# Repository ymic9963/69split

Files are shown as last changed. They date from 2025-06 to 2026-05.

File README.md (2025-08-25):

# 69SPLIT Keyboard
A split keyboard with 69 keys made for people that like to expose their I/O for any usecase.

## Costs
- Keycaps              = £3.38
- USB2.0 USB-C cable   = £0.80 
- Stabilisers          = £4.92
- Rubber feet          = £1.47
- Gateron Switches     = £15.79
- Left PCB Parts       = £10.97
- Left PCB             = £
- Right PCB Parts      = £5.36
- Left PCB             = £

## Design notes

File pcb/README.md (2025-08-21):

# PCB
Here is everything related to the PCB, with the design files for the two keyboard halves in `69split-left/` and `69split-right/`. The `3dmodels/` directory contains the 3D models I used to get the renders below. Read the `Circuit Description.md` file for a description on the design.

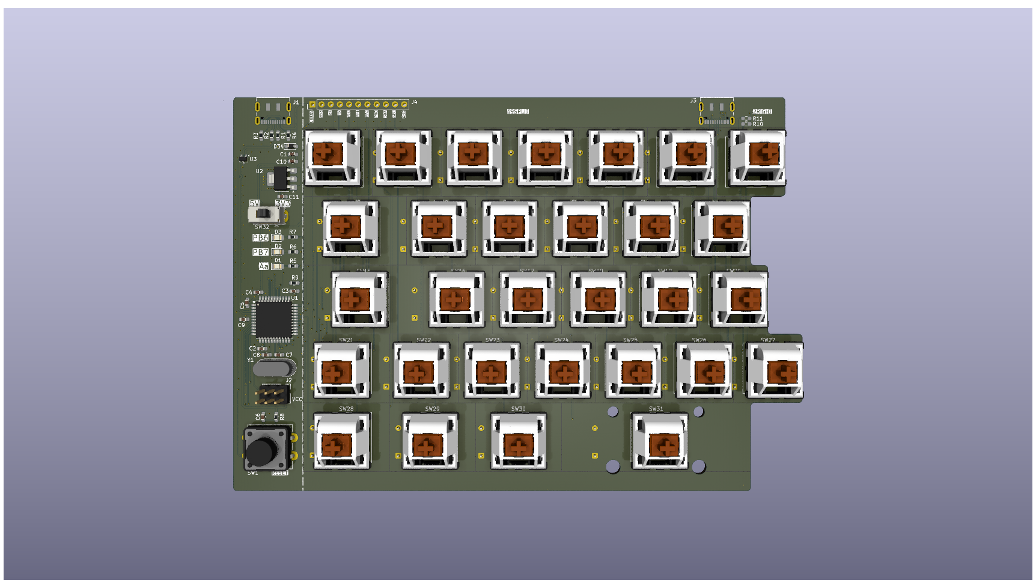
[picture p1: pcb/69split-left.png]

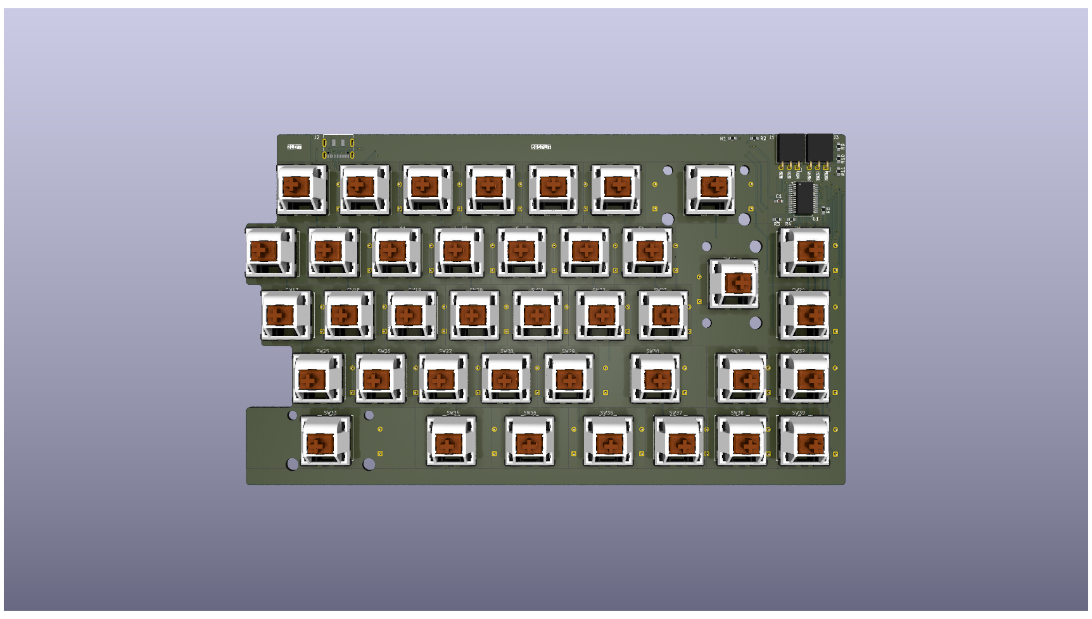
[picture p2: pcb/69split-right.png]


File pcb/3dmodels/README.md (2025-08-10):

# 3D Models
Used the `SW_Cherry_MX_PCB.stp` file from the [kiswitch](https://github.com/kiswitch/kiswitch/tree/main/library/3dmodels/3d-library.3dshapes) (Keyswitch KiCAD Livrary), and renamed it to get the models for the keyswitches used in the project. Place it in your KiCAD 3D model directory. Unfortunately I had to add offsets of X: -2.5mm, Y:-5mm, and Z:-0.5mm in all of the corresponding footprint files so that the models would align nicely.

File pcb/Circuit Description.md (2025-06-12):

# PROJECT-TITLE Circuit Description

## ATmega32U4
- Used this processor because it's compatible with QMK. Has a built in USB controller.
- 5V supply via USB.
- Minimum 500R current limiting resistors on GPIO pins as seen on Table 29-1 of the datasheet. 
- USB Implementation based on Section 21.3 Typical Application Implementation of datasheet.

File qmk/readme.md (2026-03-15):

# 69SPLIT

(image)

A split keyboard with 69 keys made for people that like to expose their I/O for any usecase.

* Keyboard Maintainer: [Yiannis Michael](https://github.com/ymich9963)
* Hardware Supported: rev1
* Hardware Availability: N/A

Make example for this keyboard (after setting up your build environment):

    make 69SPLIT

Flashing example for this keyboard:

    make 69SPLIT:default:flash

See the [build envronment setup](https://docs.qmk.fm/newbs_getting_started) and the [make instructions](https://docs.qmk.fm/getting_started_make_guide) for more information. Brand new to QMK? Start with our [Complete Newbs Guide](https://docs.qmk.fm/newbs).

## Bootloader

Enter the bootloader with the RESET button.

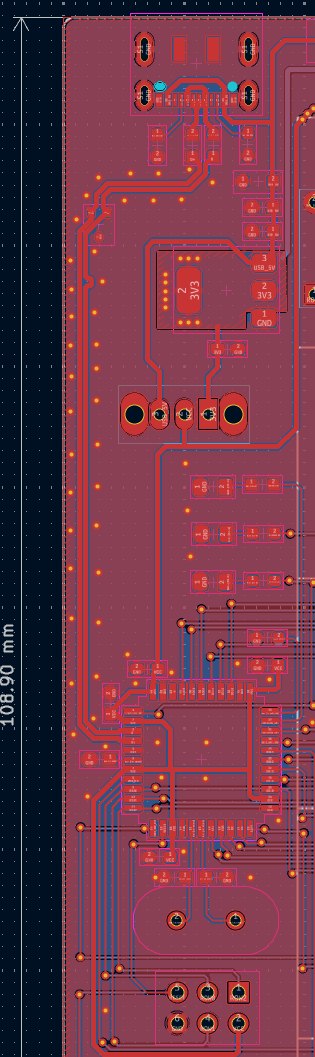
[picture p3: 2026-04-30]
pcb/69split-left/keeb-layout.png

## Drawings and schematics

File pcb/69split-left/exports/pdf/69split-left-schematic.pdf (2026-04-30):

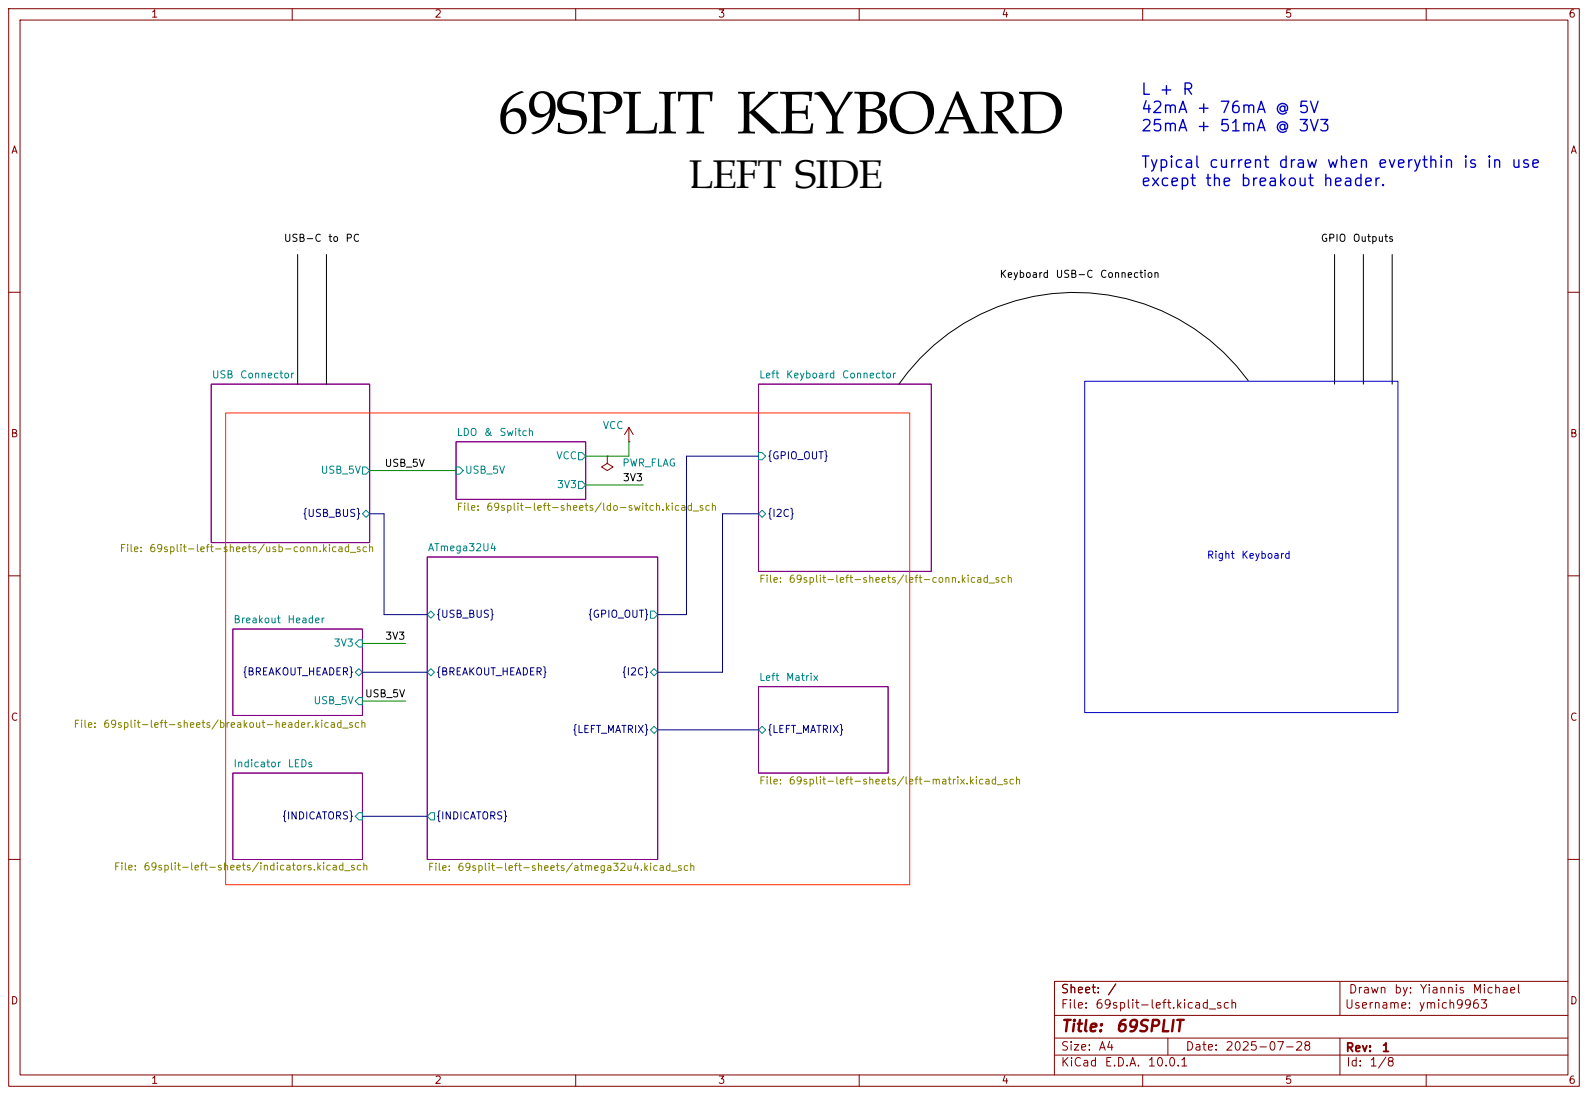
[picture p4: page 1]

Keyboard USB-C Connection 69SPLIT KEYBOARD L + R

Typical current draw when everythin is in use
except the breakout header. GPIO Outputs

{USB_BUS} USB_5V USB Connector File: 69split-left-sheets/usb-conn.kicad_sch

{I2C} Left Keyboard Connector File: 69split-left-sheets/left-conn.kicad_sch USB_5V

File: 69split-left-sheets/ldo-switch.kicad_sch

{BREAKOUT_HEADER} 3V3 USB_5V Breakout Header File: 69split-left-sheets/breakout-header.kicad_sch

{LEFT_MATRIX} Left Matrix File: 69split-left-sheets/left-matrix.kicad_sch

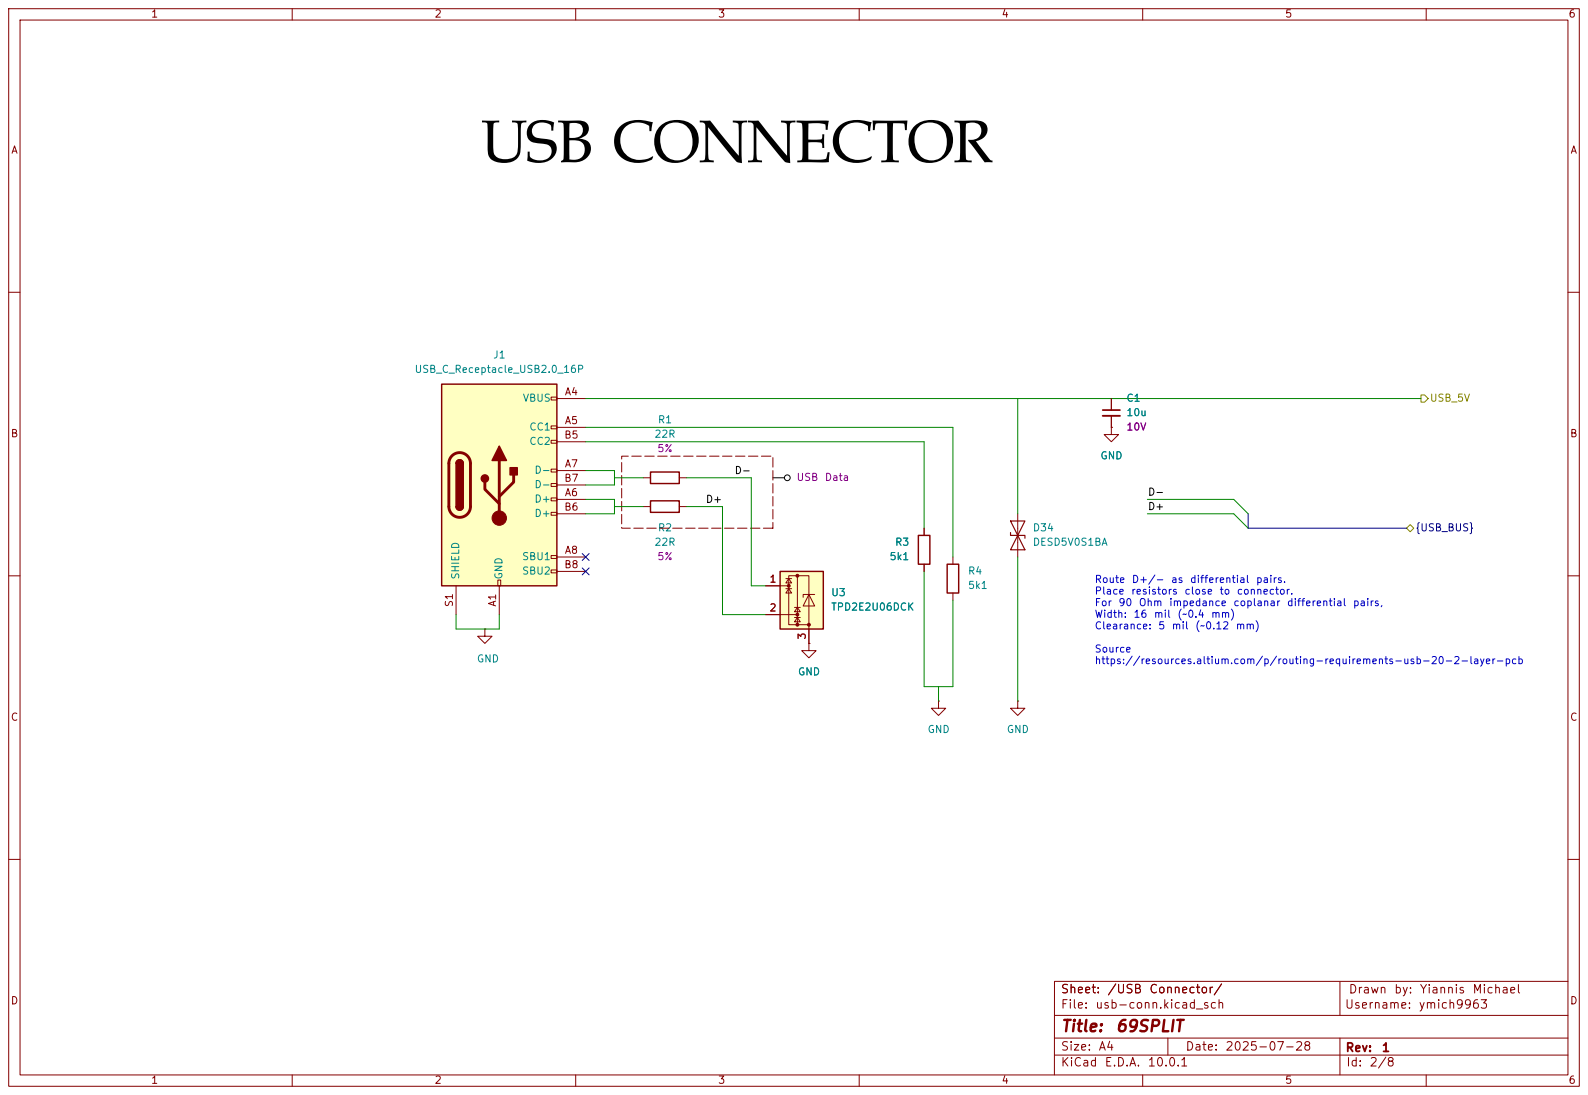
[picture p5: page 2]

Route D+/- as differential pairs. Place resistors close to connector. For 90 Ohm impedance coplanar differential pairs, Width: 16 mil (~0.4 mm) Clearance: 5 mil (~0.12 mm) Source https://resources.altium.com/p/routing-requirements-usb-20-2-layer-pcb U3

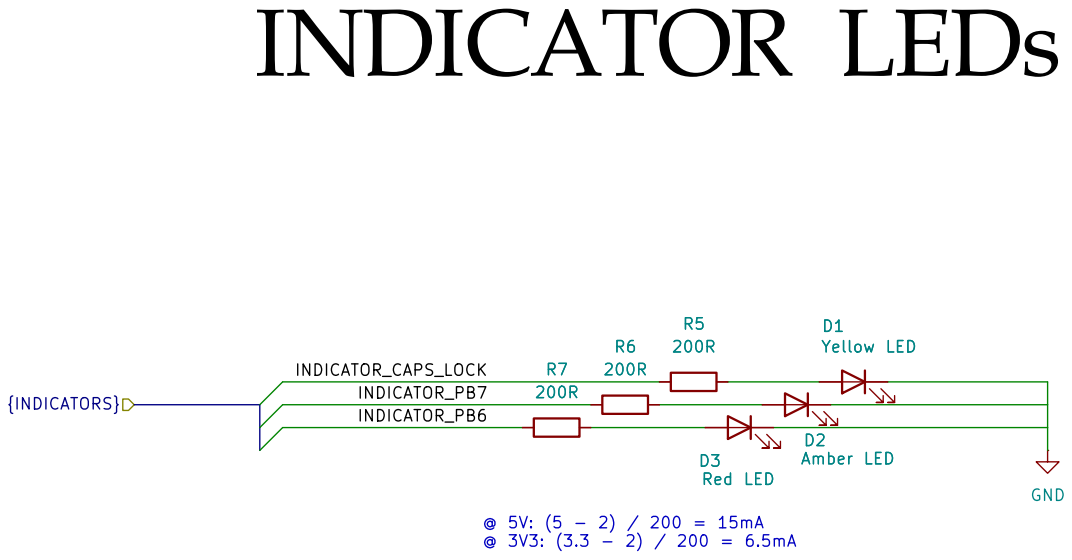
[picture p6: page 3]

Size: A5 | Rev: 1 | C Date: 2025-07-28
KiCad E.D.A. 10.0.1 | Id: 3/8

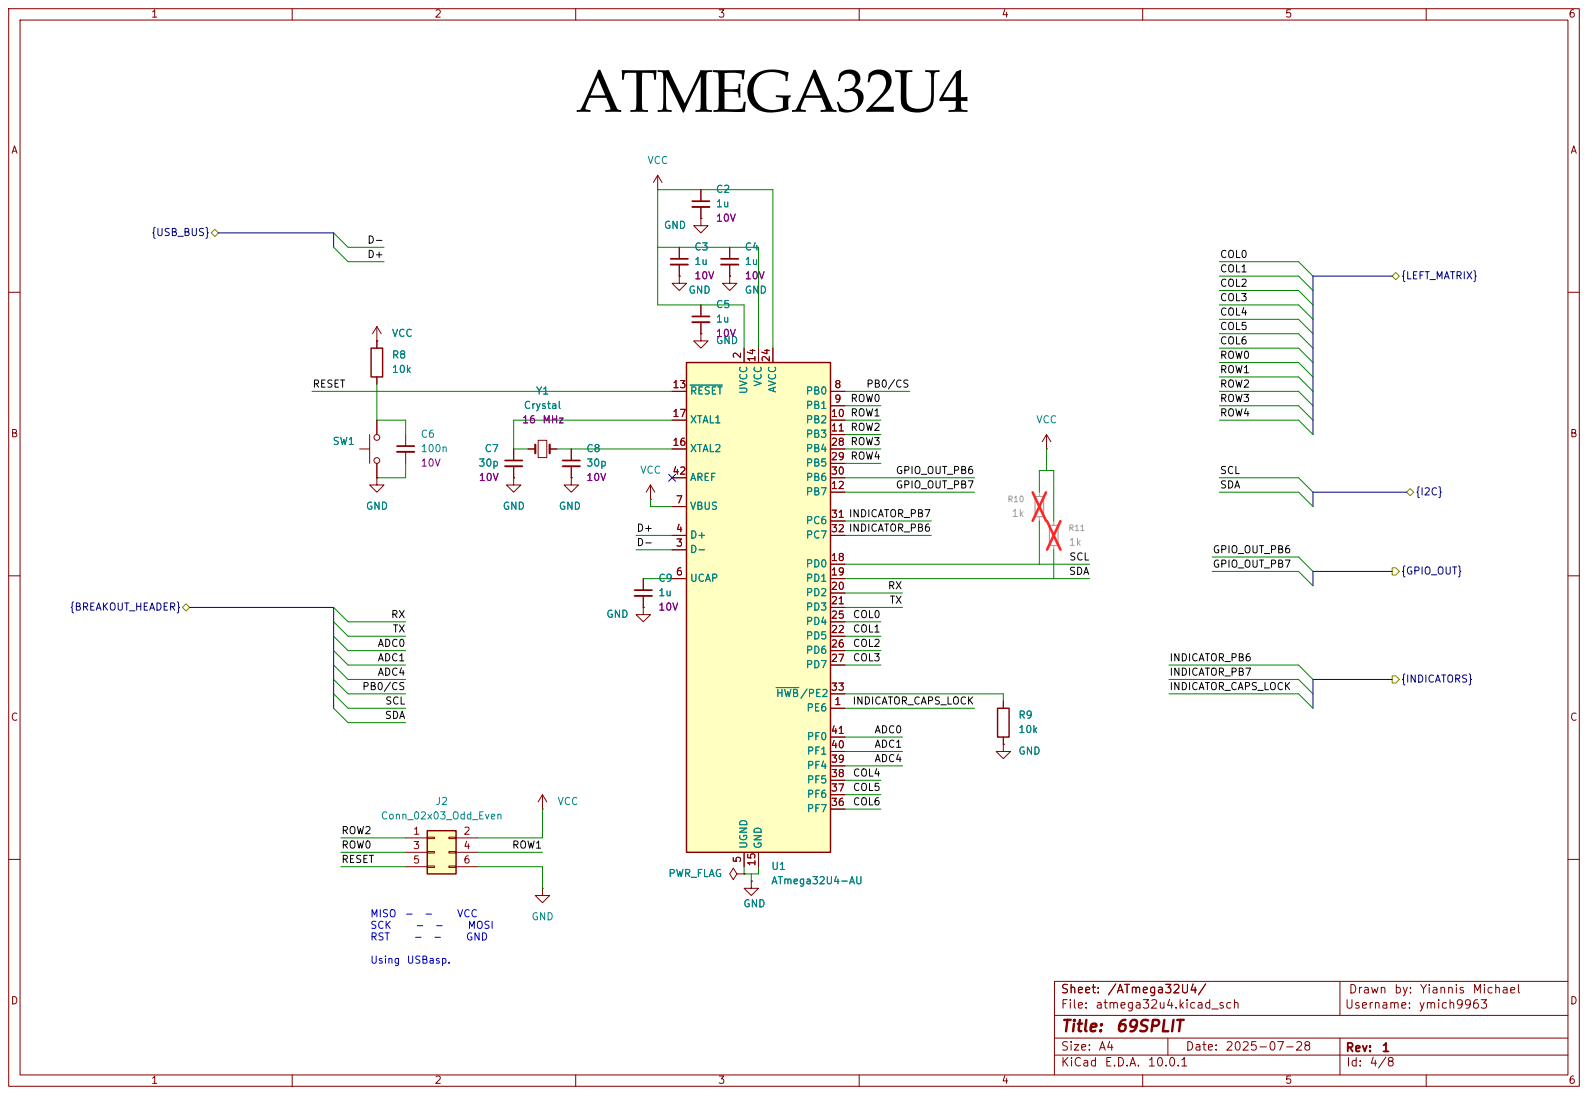
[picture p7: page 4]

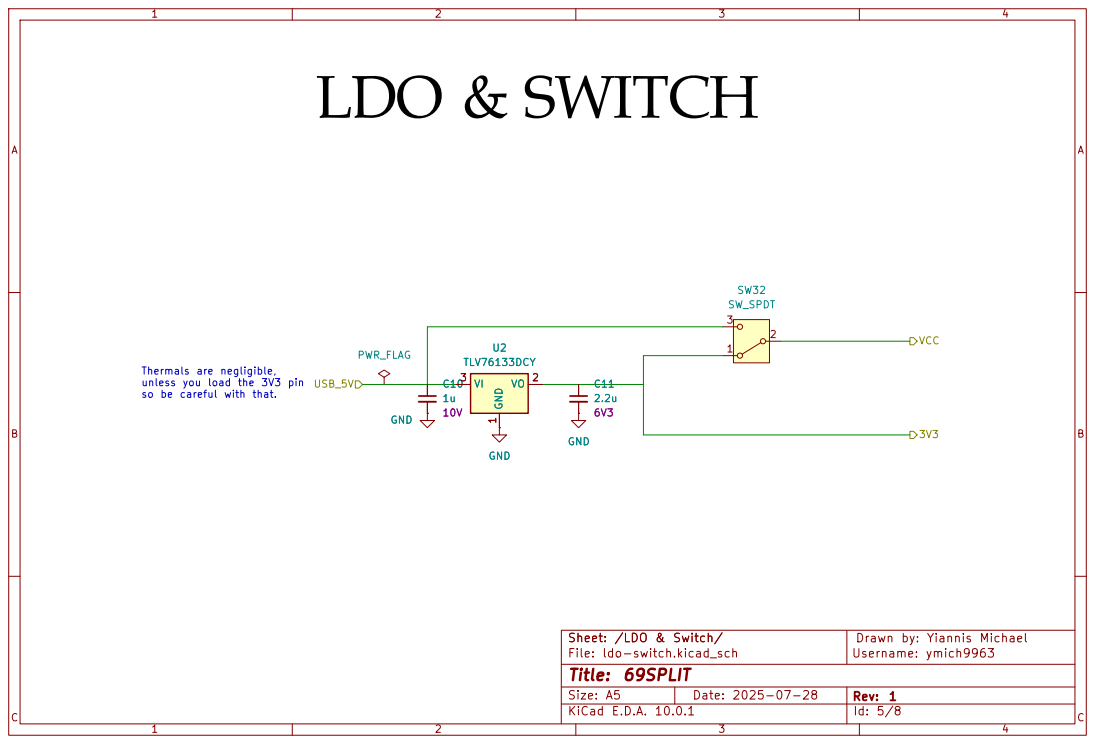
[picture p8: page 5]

Thermals are negligible, unless you load the 3V3 pin

Size: A5 | Rev: 1 | C Date: 2025-07-28
KiCad E.D.A. 10.0.1 | Id: 5/8

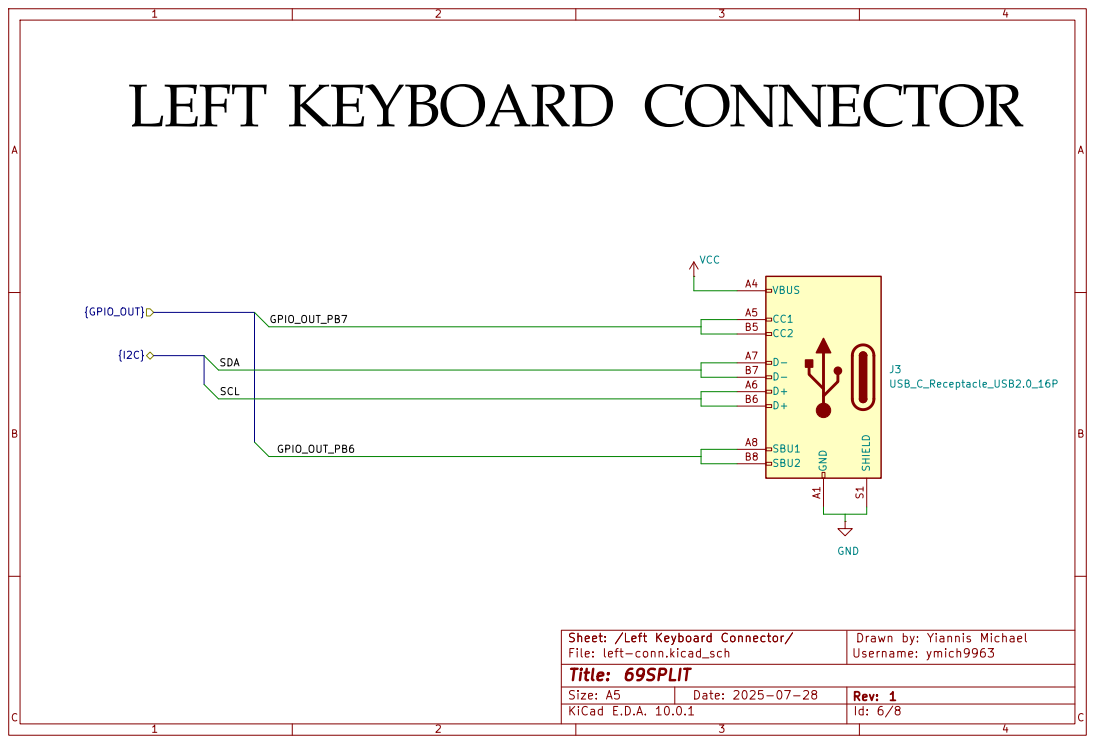
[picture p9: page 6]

Size: A5 | Rev: 1 | C Date: 2025-07-28
KiCad E.D.A. 10.0.1 | Id: 6/8

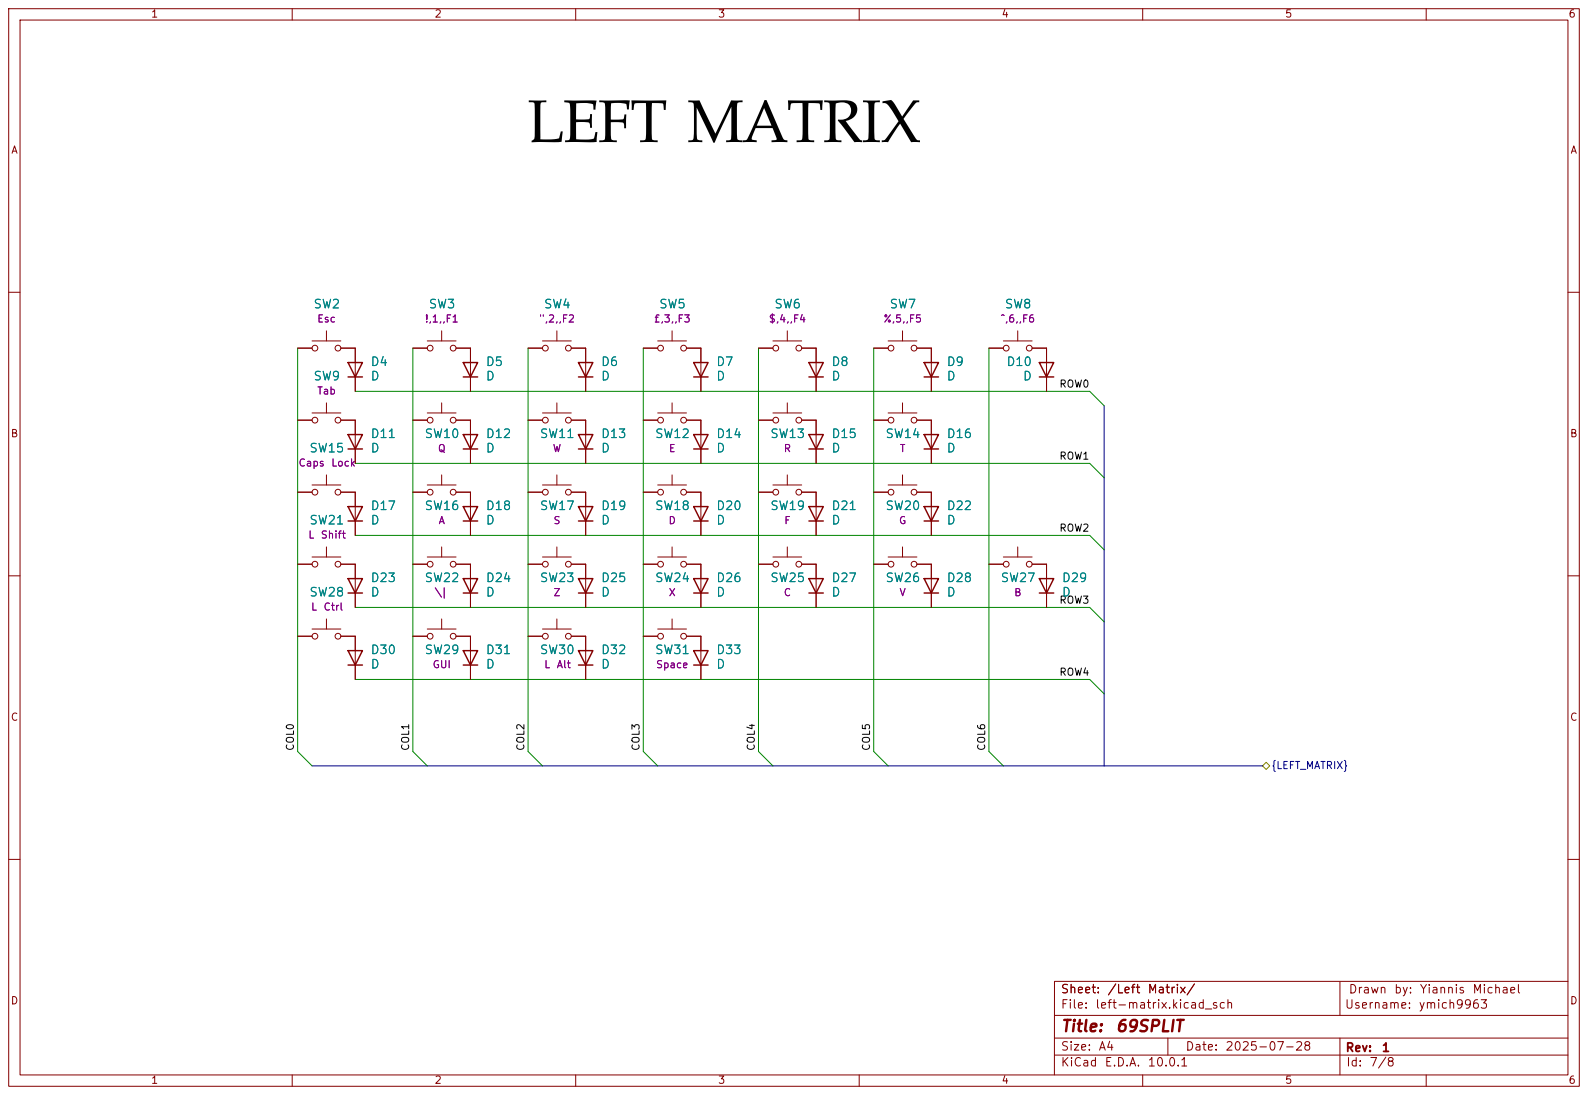
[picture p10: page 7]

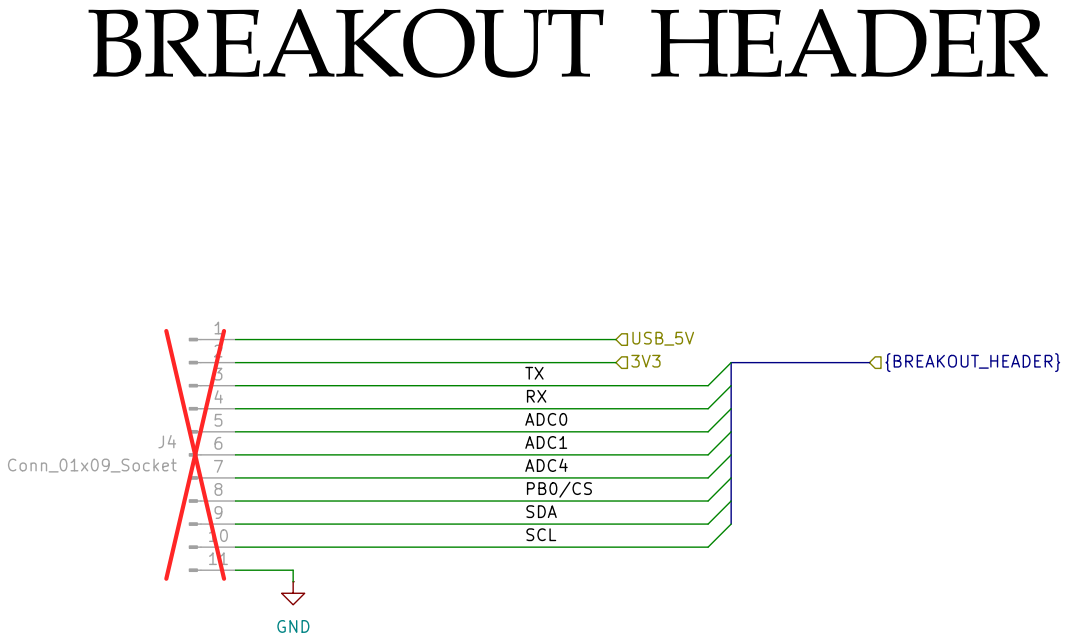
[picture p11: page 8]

Size: A5 | Rev: 1 | C Date: 2025-07-28
KiCad E.D.A. 10.0.1 | Id: 8/8

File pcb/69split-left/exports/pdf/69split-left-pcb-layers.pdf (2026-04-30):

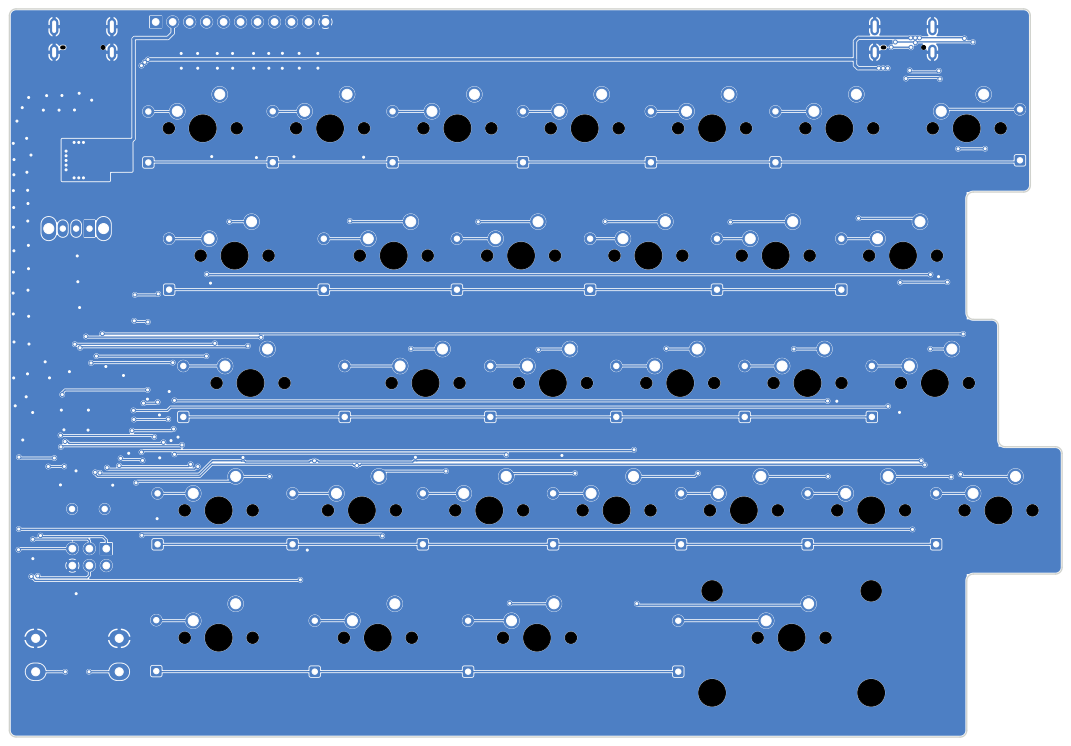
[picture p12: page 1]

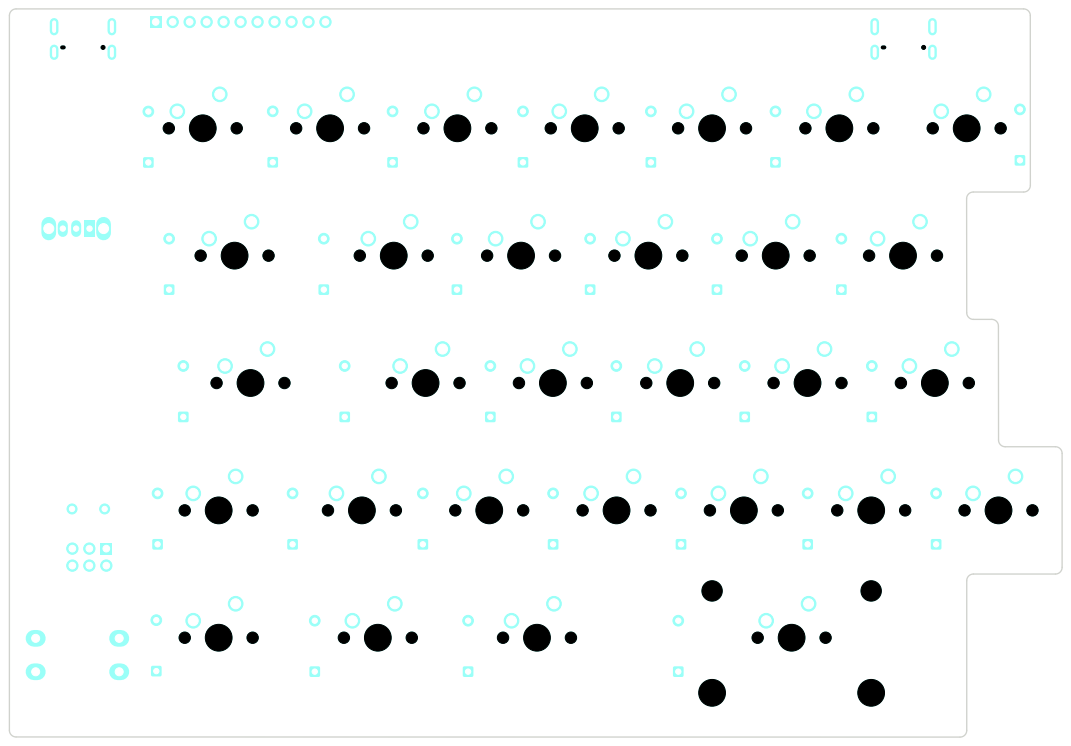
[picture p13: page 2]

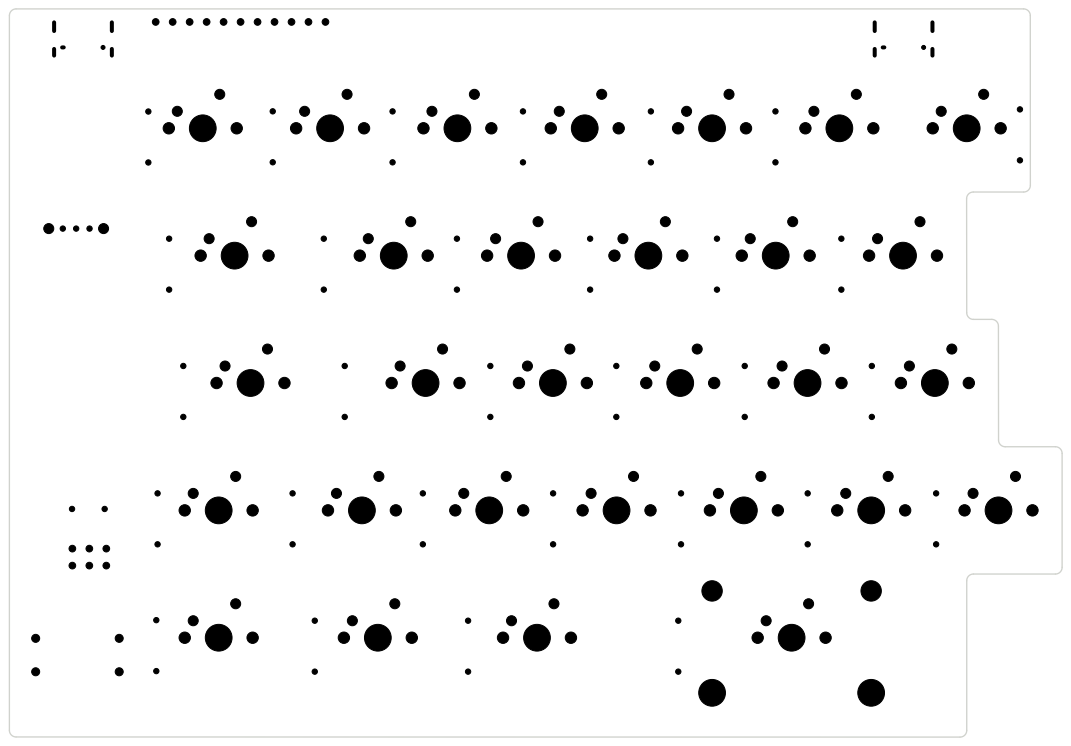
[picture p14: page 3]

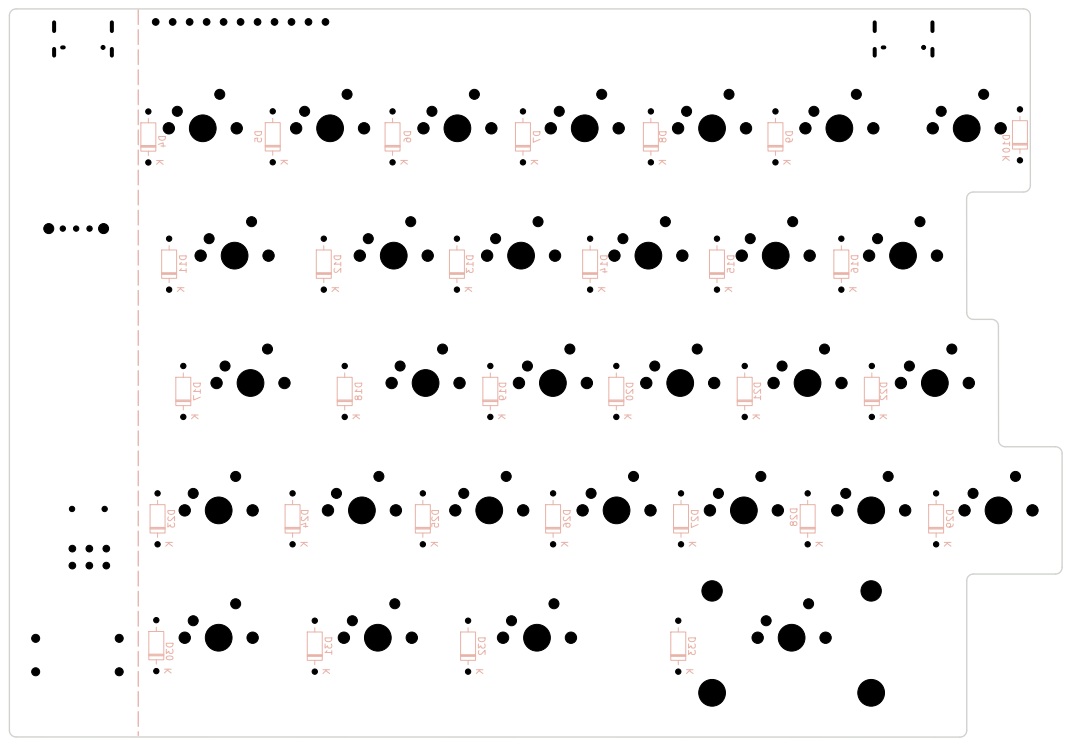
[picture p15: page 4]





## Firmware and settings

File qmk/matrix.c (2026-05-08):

#include <stdbool.h>
#include <string.h>
#include "i2c_master.h"
#include "wait.h"
#include "mcp23018.h"
#include "atomic_util.h"
#include "matrix.h"
#include "gpio.h"
#include "config.h"

#define IOEXPANDER_COLS_START_INDEX 7
#define IOEXPANDER_ADDR 0x20
#define IOEXPANDER_COLS_PORT mcp23018_PORTA
#define IOEXPANDER_ROWS_PORT mcp23018_PORTB

static pin_t row_pins[MATRIX_ROWS_PER_HAND] = MATRIX_ROW_PINS;
static pin_t col_pins[MATRIX_COLS] = MATRIX_COL_PINS;

/* From qmk_firmware/quantum/matrix.c */
static inline void gpio_atomic_set_pin_output_low(pin_t pin) {
    ATOMIC_BLOCK_FORCEON {
        gpio_set_pin_output(pin);
        gpio_write_pin_low(pin);
    }
}

/* From qmk_firmware/quantum/matrix.c */
static inline void gpio_atomic_set_pin_input_high(pin_t pin) {
    ATOMIC_BLOCK_FORCEON {
        gpio_set_pin_input_high(pin);
    }
}

// TODO: create set output high and input low
static inline uint8_t mcp23018_read_pin(uint8_t port, uint8_t pin) {
    uint8_t pins = 0;
    mcp23018_read_pins(IOEXPANDER_ADDR, port, &pins);

    uint8_t pin_mask = 1 << pin;
    uint8_t pin_value = pins & pin_mask;

    return (pin_value == 0) ? 0 : 1;
}

static inline void mcp23018_set_pin_input_high(uint8_t port, uint8_t pin) {
    uint8_t cur_port_value = 0;
    mcp23018_read_pins(IOEXPANDER_ADDR, port, &cur_port_value);

    uint8_t row_port = 1 << pin;
    uint8_t conf = cur_port_value & ~(row_port); // clear bit first
    conf |= row_port; // set bit

    mcp23018_set_config(IOEXPANDER_ADDR, port, conf);
}

static inline void mcp23018_set_pin_output_low(uint8_t port, uint8_t pin) {
    uint8_t cur_port_value = 0;
    mcp23018_read_pins(IOEXPANDER_ADDR, port, &cur_port_value);

    uint8_t row_port = ~(1 << pin);
    uint8_t conf = cur_port_value & row_port;

    mcp23018_set_config(IOEXPANDER_ADDR, port, conf);
    mcp23018_set_output(IOEXPANDER_ADDR, port, conf);
}

/* Adapted from qmk_firmware/quantum/matrix.c */
static bool select_row(uint8_t row) {
    pin_t pin = row_pins[row];
    if (pin != NO_PIN) {
        // Selecting the rows must happen on both MCU and IO expander
        gpio_atomic_set_pin_output_low(pin);
        mcp23018_set_pin_output_low(IOEXPANDER_ROWS_PORT, row); // comment out for default
        return true;
    }
    return false;
}

/* Adapted from qmk_firmware/quantum/matrix.c */
static void unselect_row(uint8_t row) {
    pin_t pin = row_pins[row];
    if (pin != NO_PIN) {
        // Unselecting the rows must happen on both MCU and IO expander
        gpio_atomic_set_pin_input_high(pin);
        mcp23018_set_pin_input_high(IOEXPANDER_ROWS_PORT, row);
    }
}

/* From qmk_firmware/quantum/matrix.c */
static inline uint8_t readMatrixPin(pin_t pin) {
    if (pin != NO_PIN) {
        return (gpio_read_pin(pin) == 0) ? 0 : 1;
    } else {
        return 1;
    }
}

 /* Adapted from qmk_firmware/quantum/matrix.c */
void matrix_read_cols_on_row(matrix_row_t current_matrix[], uint8_t current_row) {
    // Start with a clear matrix row
    matrix_row_t current_row_value = 0;

    if (!select_row(current_row)) { // Select row
        return;                     // skip NO_PIN row
    }

    matrix_output_select_delay();

    // For each col...
    matrix_row_t row_shifter = MATRIX_ROW_SHIFTER;
    for (uint8_t col_index = 0; col_index < MATRIX_COLS; col_index++, row_shifter <<= 1) {
        uint8_t pin_state = 0;
        if (col_index < IOEXPANDER_COLS_START_INDEX) {
            pin_state = readMatrixPin(col_pins[col_index]);
        } else {
            pin_state = mcp23018_read_pin(IOEXPANDER_COLS_PORT, col_index - IOEXPANDER_COLS_START_INDEX );
        }

        // Populate the matrix row with the state of the col pin
        current_row_value |= pin_state ? 0 : row_shifter;
    }

    // Unselect row
    unselect_row(current_row);

    matrix_output_unselect_delay(current_row, current_row_value != 0); // wait for all Col signals to go HIGH

    // Update the matrix
    current_matrix[current_row] = current_row_value;
}

 /* Adapted from qmk_firmware/drivers/gpio/mcp23018.c to reduce delay */
void mcp23018_init_fast(uint8_t addr) {
    static uint8_t s_init = 0;
    if (!s_init) {
        i2c_init();
        wait_ms(10);

        s_init = 1;
    }
}

 /* Adapted from qmk_firmware/quantum/matrix.c */
void matrix_init_custom(void) {
    /* Initialise matrix pins */
    for (uint8_t x = 0; x < MATRIX_ROWS; x++) {
        if (row_pins[x] != NO_PIN) {
            gpio_atomic_set_pin_input_high(row_pins[x]);
        }
    }

    for (uint8_t x = 0; x < MATRIX_COLS; x++) {
        if (col_pins[x] != NO_PIN) {
            gpio_atomic_set_pin_input_high(col_pins[x]);
        }
    }

    /* Initialise IO Expander */
    mcp23018_init_fast(IOEXPANDER_ADDR);

    /* Set port A (rows) to all input with pull-up enabled */
    if (mcp23018_set_config(IOEXPANDER_ADDR, IOEXPANDER_COLS_PORT, ALL_INPUT) == false) {
        gpio_write_pin_high(C6);
        return;
    }

    /* Set port B (rows) to all input with pull-up enabled */
    if (mcp23018_set_config(IOEXPANDER_ADDR, IOEXPANDER_ROWS_PORT, ALL_INPUT) == false) {
        gpio_write_pin_high(C7);
        return;
    }
}

/* Called in qmk_firmware/quantum/matrix_common.c
 * Adapted from qmk_firmware/quantum/matrix.c
 * */
bool matrix_scan_custom(matrix_row_t raw_matrix[]) {
    matrix_row_t curr_matrix[MATRIX_ROWS] = {0};

    for (uint8_t current_row = 0; current_row < MATRIX_ROWS; current_row++) {
        matrix_read_cols_on_row(curr_matrix, current_row);
    }

    bool changed = memcmp(raw_matrix, curr_matrix, sizeof(curr_matrix)) != 0;
    if (changed) memcpy(raw_matrix, curr_matrix, sizeof(curr_matrix));

    return changed;
}

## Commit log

2025-06-10 Continued development. Fixed the keyboard connections. Trying to figure out how to connect them together.
    [left.kicad_sch, right.kicad_sch, split-normal-69.kicad_sch]
2025-06-10 Moved things around more so that they make sense. Slowly figuring it out.
    [atmega32u4.kicad_sch, left-conn.kicad_sch, left.kicad_sch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]
2025-06-13 Added MPNs and footprints for I think everything.
    [atmega32u4.kicad_sch, left-conn.kicad_sch, left-matrix.kicad_sch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]
2025-06-16 Continuing...no one will read this but me.
    [69split-left.kicad_pcb, 69split-left.kicad_sch, 69split-right.kicad_pcb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]
2025-06-18 Figured out what GPIOs to use.
    [69split-left.kicad_sch, 69split-right.kicad_sch, 69split.kicad_sch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]
2025-06-18 I think schematic is done?
    [69split-right.kicad_sch, 69split.kicad_sch, atmega32u4.kicad_sch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]
2025-06-18 Moved things around so it's less confusing.
    [69split-left.kicad_sch, 69split-right.kicad_sch, 69split.kicad_sch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]
2025-06-19 Started layout?
    [69split-left.kicad_pcb, 69split-left.kicad_sch, atmega32u4.kicad_sch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]
2025-06-29 Continued layout.
    [69split-left.kicad_pcb, 69split-left.kicad_sch, 69split-right.kicad_sch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]
2025-07-26 Practically finished the left side - need to make a footprint for the split USB connector. Some other schematic changes were made that I will not list. I should've made more commits between ths one a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
    [69split-left.kicad_pcb, 69split-left.kicad_sch, atmega32u4.kicad_sch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]
2025-08-07 Started changing things gain to use an I/O expander with I2C.
    [69split-left.kicad_pcb, 69split-left.kicad_sch, 69split-right.kicad_pcb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]
2025-08-07 Continuing with I/O expander integration.
    [69split-left.kicad_pcb, 69split-right.kicad_pcb, io-expander.kicad_sch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]
2025-08-10 Finished left keyboard again...
    [69split-left.kicad_pcb, 69split-left.kicad_sch, SW_Cherry_MX_PCB.stp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]
2025-08-11 Minor improvements to left schematic and layout.
    [69split-left.kicad_pcb, 69split-right.kicad_pcb, atmega32u4.kicad_sch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]
2025-08-14 Alright I think now the left side is actually ready.
    [69split-left.kicad_pcb, 69split-right.kicad_pcb, 69split-right.kicad_sch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]
2025-08-15 First draft of the right side.
    [69split-right.kicad_pcb, 69split-right.kicad_sch, gpio.kicad_sch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]
2025-08-17 I think the right side is done???. Added image and 3D files.
    [69split-left.kicad_sch, 69split-right.kicad_pcb, right-conn.kicad_sch]
2025-08-18 Finished design and layout?
    [69split-left.kicad_pcb, 69split-left.kicad_sch, 69split-right.kicad_pcb]
2025-08-18 Added silkscreen for ATmega and MCP pins.
    [69split-right.kicad_pcb]
2025-08-19 Added ESD protection and better routing for the USB data lines.
    [69split-left.kicad_pcb, breakout-header.kicad_sch, ldo-jumper.kicad_sch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]
2025-08-21 Added SPDT switch because I do not want to wait for the KiCAD librarians to approve of my SP3T switch, therefore that will be in future work.
    [69split-left.kicad_pcb, 69split-left.kicad_sch, ldo-switch.kicad_sch]
2025-08-21 Added and updated READMEs and some other minor changes.
    [69split-right.kicad_pcb]
2025-08-22 Final touches.
    [69split-left.kicad_pcb, 69split-left.kicad_sch, 69split-right.kicad_sch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]
2025-08-23 More final touches fml.
    [69split-left.kicad_pcb, 69split-left.kicad_sch, 69split-right.kicad_pcb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]
2025-08-25 Ordered the PCBs and parts!
    [69split-left.kicad_pcb, 69split-right.kicad_pcb, atmega32u4.kicad_sch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]
2026-03-13 Fix column number labels
    Before it started from COL6 but it should start from COL7 because COL6
    is on the left PCB.
    [69split-right.kicad_pcb, io-expander.kicad_sch, right-matrix.kicad_sch]
2026-03-16 Update key names
    Change Win to GUI and specify L/R Alt, L/R Shift, and L/R Ctrl
    [left-matrix.kicad_sch, right-matrix.kicad_sch]
2026-03-23 Add LED initialisations
2026-04-02 Update files to KiCad 10
    [69split-left.kicad_pcb, 69split-left.kicad_sch, 69split-right.kicad_pcb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]
2026-04-18 Update crystal frequency and MPN
    [atmega32u4.kicad_sch]
